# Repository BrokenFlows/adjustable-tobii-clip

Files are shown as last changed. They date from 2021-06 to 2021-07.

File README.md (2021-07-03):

# Adjustable Tobii Clip
A 3D Printable, adjustable, clip for holding a Tobii eye-tracker onto a laptop.
A photo showing the eye-tracker clip in use

This clip is designed to accommodate laptops between the thickness of the 2021 M1 MacBooks and the Dell Latitude E7470.

## Notes on Assembly and Usage
A video on how to assemble the eye-tracker clip can be found [here](https://youtu.be/O6Jt8ge1TOA). Written instructions can be found below.

### Step Zero
Start the assembly with all the pieces laid out in front of you. 
The two long pieces are the clips, the two middle-sized pieces are the stoppers, and the two smallest pieces are are the end caps.
Except for the end caps, the left and right sides are asymmetric.
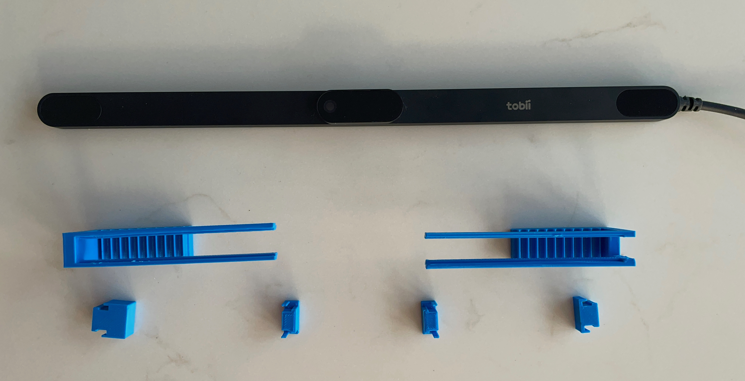
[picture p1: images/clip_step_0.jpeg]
Step zero of the eye-tracker clip assembly


### Step One
Attach the stoppers to the rails of the clips.
Thread the wire of the eye-tracker through the right clip before attaching the stopper.
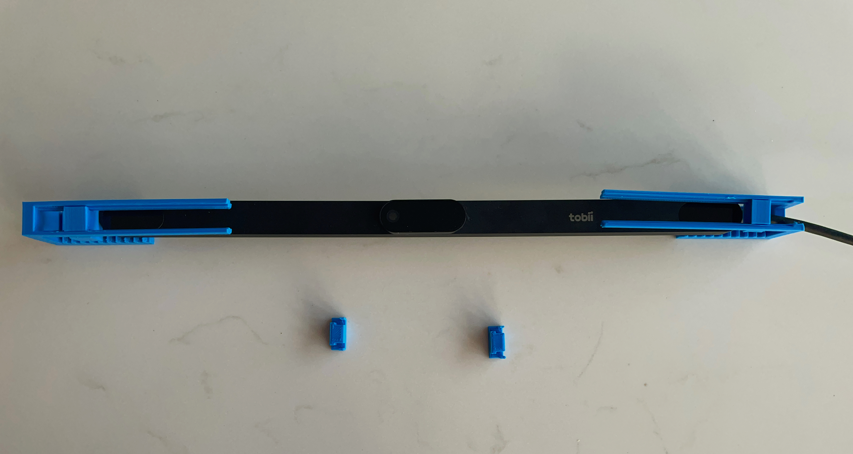
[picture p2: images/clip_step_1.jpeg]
Step one of the eye-tracker clip assembly


### Step Two
Attach the end caps to the end of the clip rails.
Set up the eye-tracker at the bottom of your laptop display, with the eye-tracker visible between the clips has shown. The back of the clip should be behind the back of the laptop lid, holding it in place.
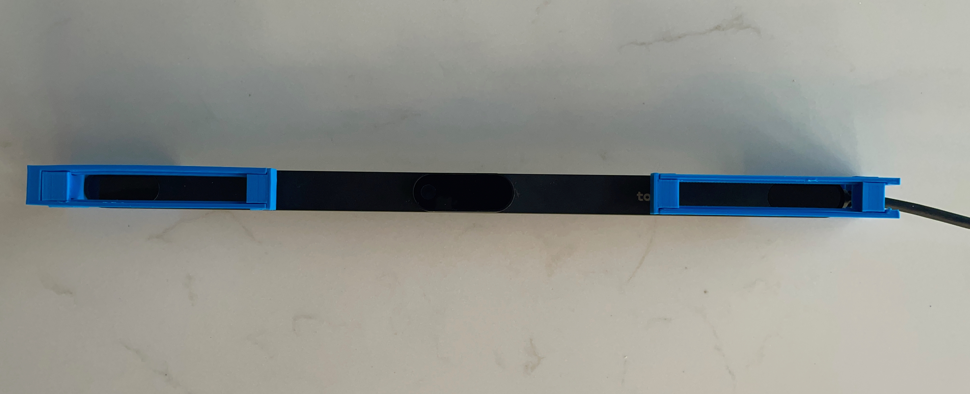
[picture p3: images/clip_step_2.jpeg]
Step two of the eye-tracker clip assembly


### Usage
The stoppers can be moved to adjust for the width of your screen, so that the Tobii eye-tracker is always centered.
The ridges at the back of the eye-tracker clip can be sanded down, clipped, or otherwise flattened to accommodate the thickness of your laptop lid.

## Notes on Printing
### Supports
In the default orientations the clips and the end caps require supports.
The end caps can be orientated to print without supports, but it makes part of the connection much more fragile.

### Nozzle Diameter
0.4 mm

### Layer Height Resolution
0.2 mm

### Infill
20% or more

### Filament
PLA

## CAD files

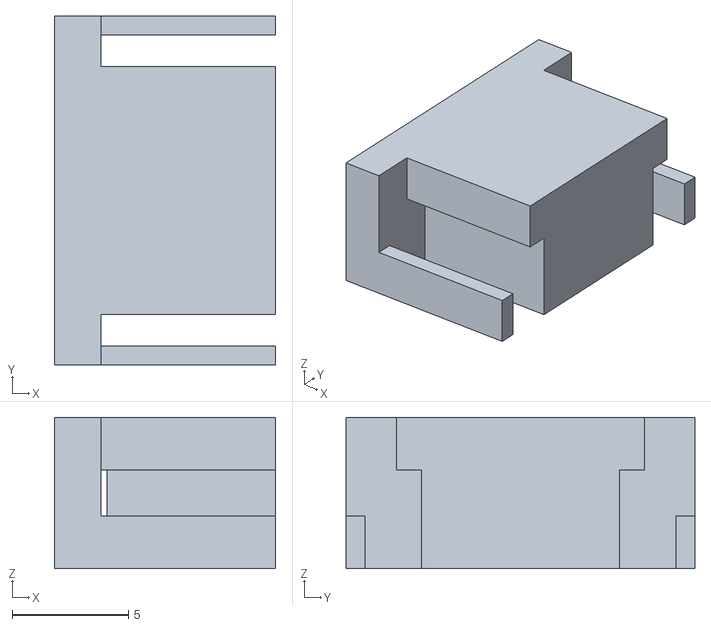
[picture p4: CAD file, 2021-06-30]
stls/left end cap.stl
9.50 x 15.0 x 6.50

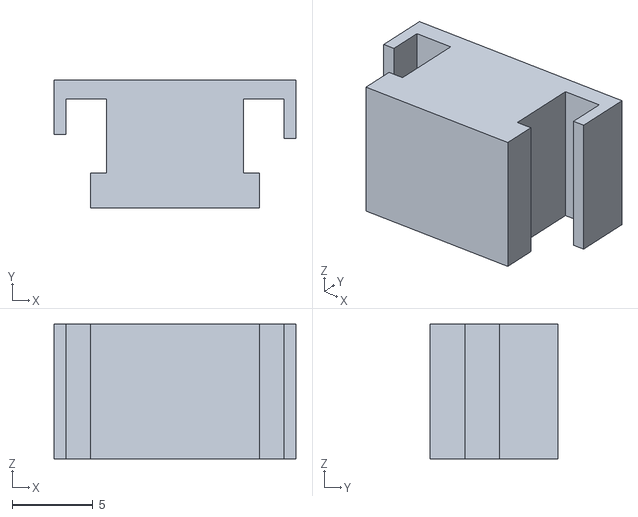
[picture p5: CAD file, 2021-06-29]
stls/right stopper.stl
15.0 x 7.95 x 8.35

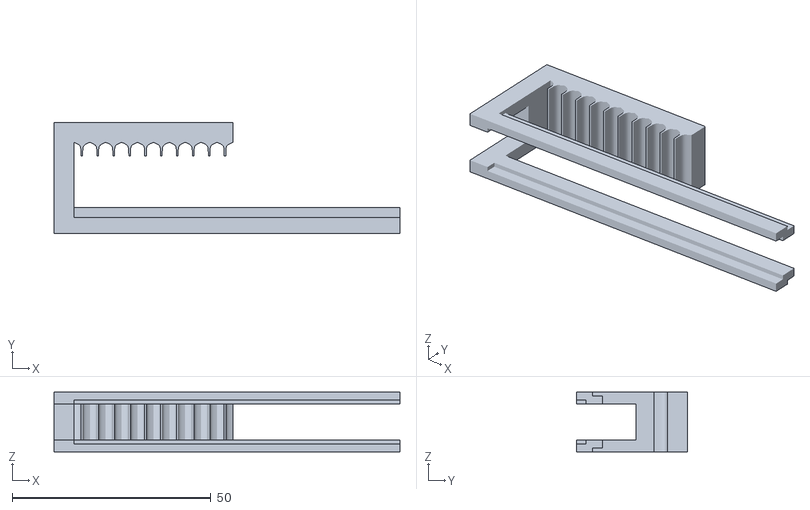
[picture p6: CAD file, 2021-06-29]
stls/right clip.stl
87.0 x 27.9 x 15.0

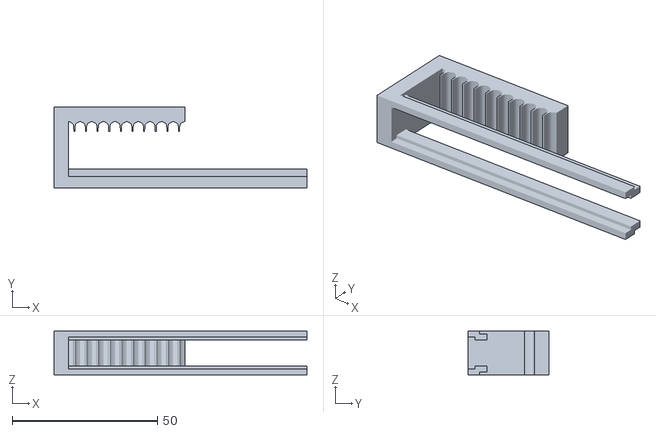
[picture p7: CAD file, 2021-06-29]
stls/left clip.stl
87.0 x 28.0 x 15.0

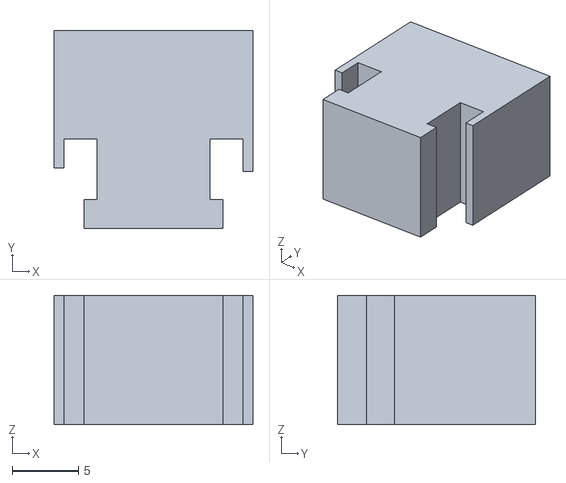
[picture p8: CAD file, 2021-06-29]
stls/left stopper.stl
15.0 x 15.0 x 9.75

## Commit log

2021-06-29 adds the stl files for the eye-tracker clips
    [left clip.stl, left end cap.stl, left stopper.stl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]
2021-06-30 rearranges README and adds link to video of assembly
2021-06-30 changes the default orientation of the end caps to make them less fragile
    [left end cap.stl, right end cap.stl]
2021-07-03 specifies nozzle diameter in README
